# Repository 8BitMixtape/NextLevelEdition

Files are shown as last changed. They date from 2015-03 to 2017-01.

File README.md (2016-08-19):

NextLevelEdition
================

SMD 32U4 Massproduction Ready PCB that fits in Mixtape

How to install
================
Download Hardware Cores from Sparkfun:
https://learn.sparkfun.com/tutorials/pro-micro--fio-v3-hookup-guide/installing-mac--linux

For Linux udev rules needs to be changed:
http://forum.arduino.cc/index.php?topic=217910.0

```
/etc/udev/rules.d/70-persistent-net.rules

 # 8Bit Mixtape NextLevel Shit
 
ATTRS{idVendor}=="1b4f", ATTRS{idProduct}=="f100", ENV{ID_MM_DEVICE_IGNORE}="1"

ATTRS{idVendor}=="1b4f", ATTRS{idProduct}=="f101", ENV{ID_MM_DEVICE_IGNORE}="1"
```

Troubleshooting
================

If the serial port doesn't appear, see above.

Strange blinking: Did you attach the LiPo battery?

Bricked the board? if you choose the wrong board and upload this might happen. solder on the ISP plug and burn the bootloader. the files is in the core.

for linux:
`avrdude -P /dev/ttyACM0 -b 19200 -c avrisp -p m32u4 -v -e -U flash:w:Caterina-fio.hex:i`

Pins:
================

2 x Analog Input
----------------
A0 ( you can also only write 0) -> D18

A1 ( you can also only write 1) -> D19

2 x Digital Input / Buttons
---------------------------
D2 (2)

D3 (3)

Sound Output
------------
D9 (9) also connected to LED2

LEDs
----
D13 (13)

the middle i don't know. maybe charge state?

RX (0)

TX (1)

Timers
============

To change the prescaler of the timer connected to Pin9 (sound output)

```
TCCR1B = TCCR0B & 0b11111001; //no timer pre-scaler, fast PWM
```

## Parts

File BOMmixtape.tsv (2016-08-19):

References | Qty | Description | Mouser | Farnell
U1 | 1 | MCP73831 | 579-MCP73831T-2ATIOT | 1840935
U5 | 1 | ATMEGA32U4 | 556-ATMEGA32U4-MU | 2425127
U6 | 1 | MIC5219-3.3 | 998-MIC5219-3.3YM5TR | 2510252RL
Q1 | 1 | BSS123 | 512-BSS123 | 9845321
Y2 | 1 | 8MHz | 717-7B-8.000MAAJ-T | 2308726
C1, C13 | 2 | 10uF | 81-GRM31CR71A106KA01
C2,C3,C6,C8,C11,C12 | 6 | 1uF | 81-GRM188R61E105KA12
C4, C14 | 2 | 0.1uF | 81-GRM39X104K50D
C5, C7 | 2 | 22pF | 81-GRM39C220J50
C9 | 1 | 4.7uF | 81-GRM18R60J475KE19D
LED1 | 1 | Yellow | 859-LTST-C190KSKT
LED2 | 1 | Red | 859-LTST-C190KGKT
LED3 | 1 | Red | 859-LTST-C190KGKT
LED4 | 1 | Blue | 859-LTST-C190TBKT
LED5 | 1 | Yellow | 859-LTST-C190KSKT
R1, R2 | 2 | 33 | 667-ERJ-3GEYJ330V
R3, R4, R7, R10, R13, R16 | 6 | 330 | 667-ERJ-3GEYJ331V
R5 | 1 | 2K | 667-ERJ-3GEYJ222V
R6, R14, R15 | 3 | 10K | 667-ERJ-3GEYJ103V
R9 | 1 | 470 | 667-ERJ-3GEYJ470V
R11, R12 | 2 | 22 | 667-ERJ-3GEYJ220V
POT_LEFT | 1 |  | 652-PTV09A-4015UB103
POT_RIGHT | 1 |  | 652-PTV09A-4015UB103
S1 | 1 | Left | 693-1301.9317 | 1217767
S3 | 1 | Right | 693-1301.9317 | 1217767
SW | 1 | SWITCH_SMD, SS SMD402, reichelt.de
SD | 1 | MICROSD | 710-693071010811 | 2081363
SPEAKER | 1 | PS603SPK | 665-AS01508MRR
X1 | 1 | USB_B_SMD | 649-10118192-0001LF | 2506104
X2 | 1 | PJ-327A, ebay
Accu | 1 | AKKU IPD SH 1G, reichelt.de

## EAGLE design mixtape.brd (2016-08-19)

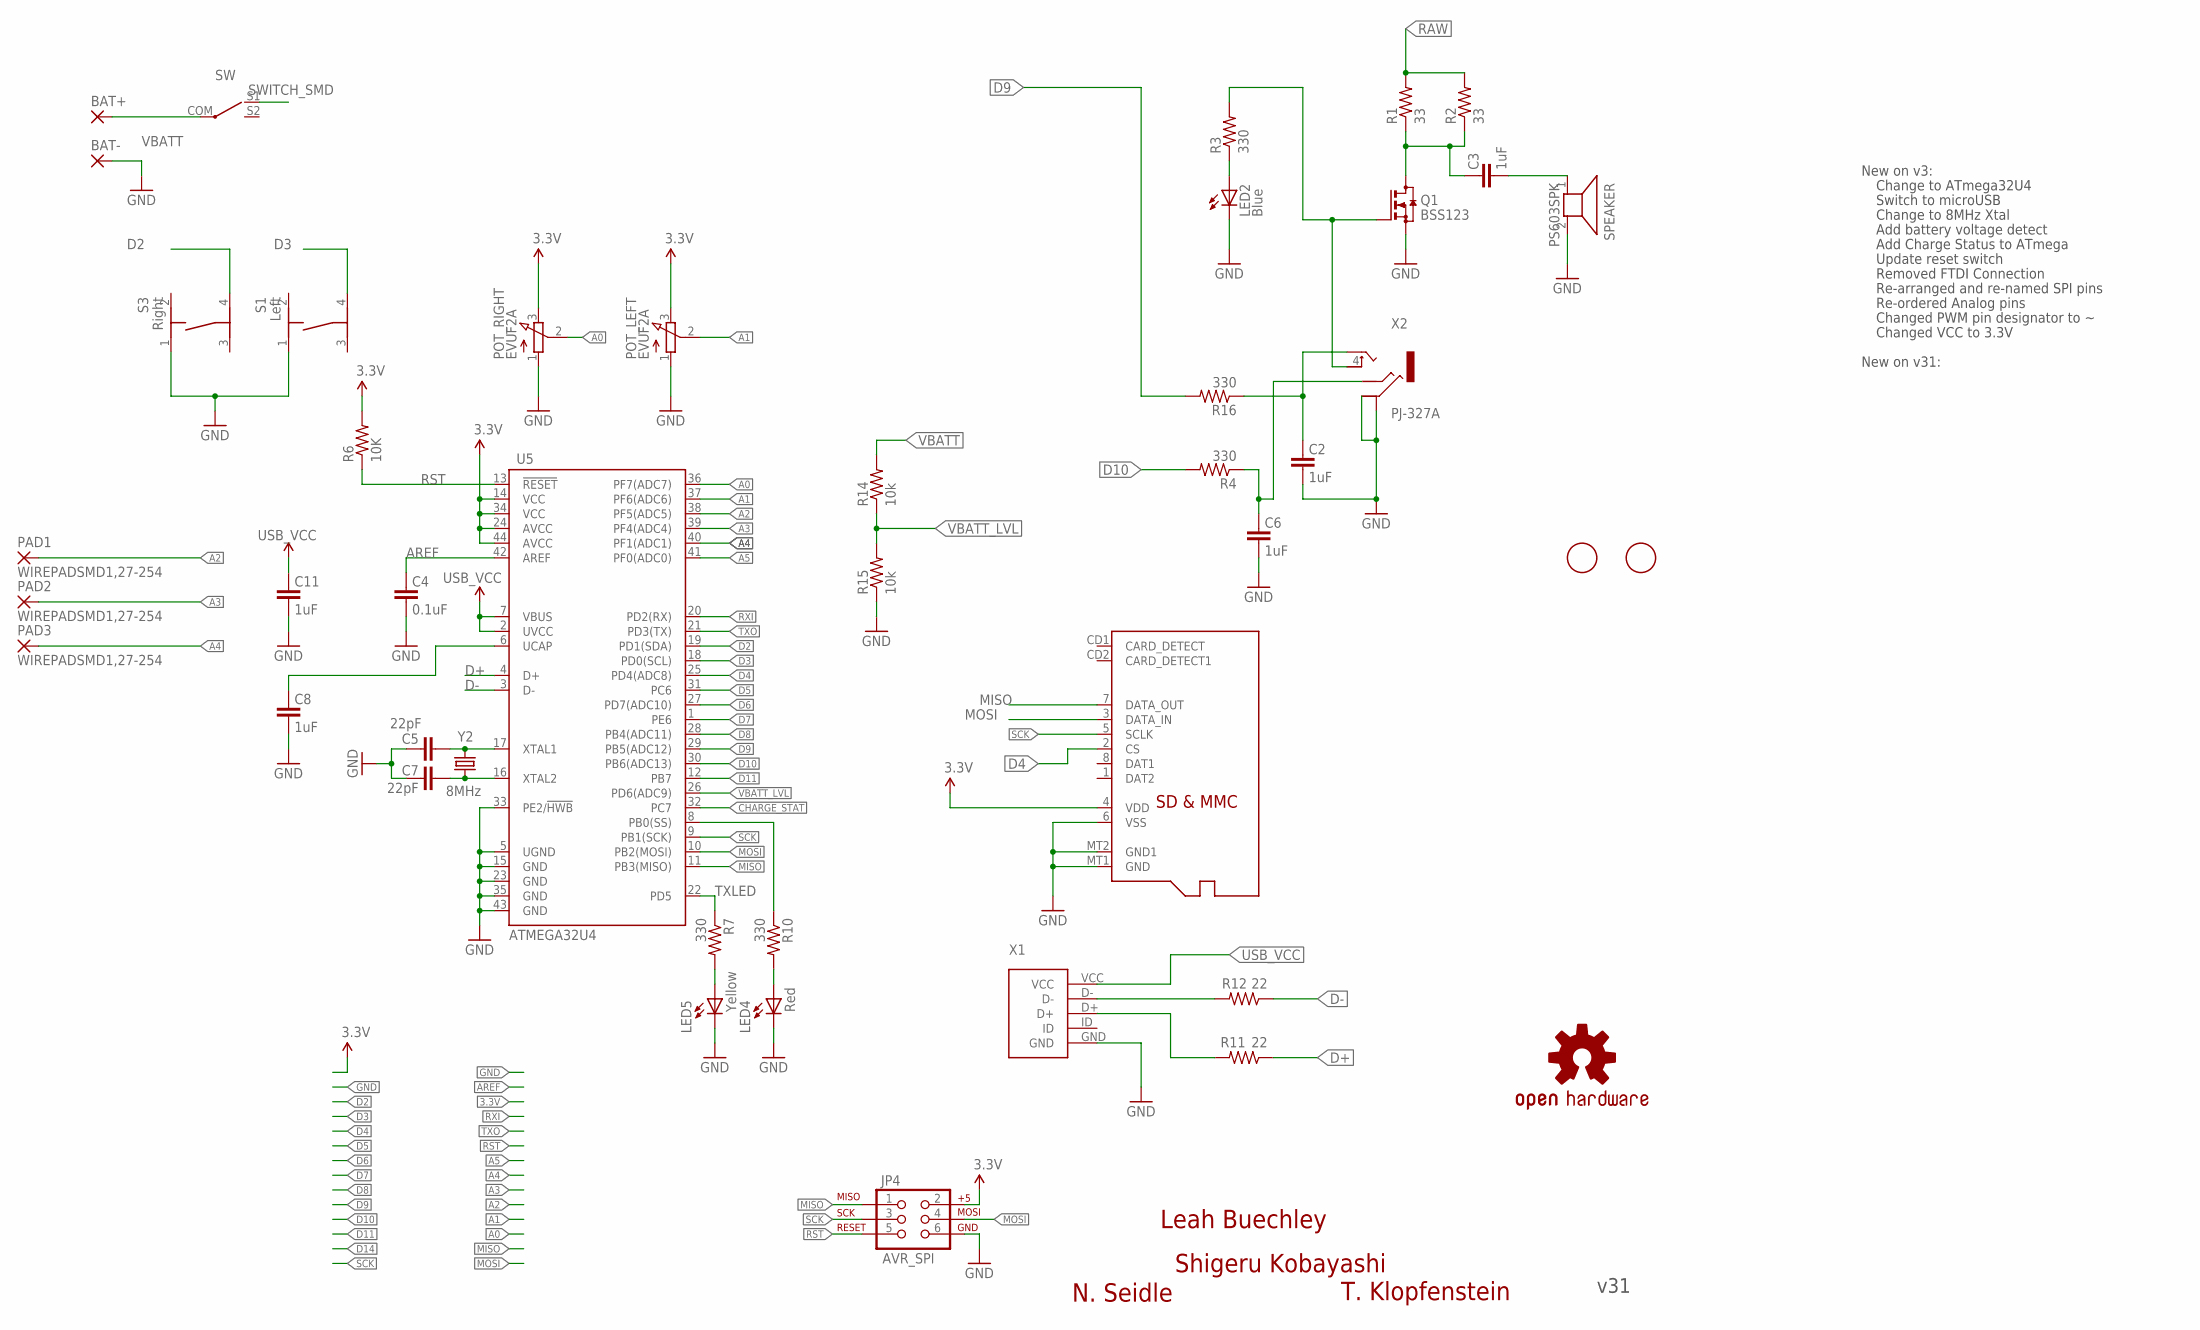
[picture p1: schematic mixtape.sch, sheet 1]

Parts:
BAT+: SMD5; SMD2,54-5,08
BAT-: SMD5; SMD2,54-5,08
C2, C3, C6, C8, C11: 1uF; 0603-CAP
C4: 0.1uF; 0603-CAP
C5, C7: 22pF; 0603-CAP
JP4: AVR_SPI; 2X3
LED2: Blue; LED-0603
LED4: Red; LED-0603
LED5: Yellow; LED-0603
LOGO1: OSHW-LOGOL; OSHW-LOGO-L
PAD1, PAD2, PAD3: WIREPADSMD1,27-254; SMD1,27-2,54
POT_LEFT: EVUF2A; EVUF
POT_RIGHT: EVUF2A; EVUF
Q1: BSS123; SOT23
R1, R2: 33; 0603-RES
R3, R4, R7, R10, R16: 330; 0603-RES
R6: 10K; 0603-RES
R11, R12: 22; 0603-RES
R14, R15: 10k; 0603-RES
S1: Left; TASTER-9314_SMD
S3: Right; TASTER-9314_SMD
SD: MICROSD
SPEAKER: PS603SPK; PS603
SW: SWITCH_SMD
U5: ATMEGA32U4; QFN-44-NOPAD_1:1
U$1, U$2: FIDUCIAL; FIDUCIAL_1MM
X1: USB_B_SMD
X2: PJ-327A
Y2: 8MHz; CRYSTAL-SMD-5X3

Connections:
3.3V: JP4.2, POT_LEFT.3 (E), POT_RIGHT.3 (E), R6.2, SD.4 (VDD), U5.14 (VCC), U5.24 (AVCC), U5.34 (VCC), U5.44 (AVCC); also elsewhere on the board
A0: POT_RIGHT.2 (S), U5.36 (PF7(ADC7))
A1: POT_LEFT.2 (S), U5.37 (PF6(ADC6))
A2: PAD1.1, U5.38 (PF5(ADC5))
A3: PAD2.1, U5.39 (PF4(ADC4))
A4: PAD3.1, U5.40 (PF1(ADC1))
A5: U5.41 (PF0(ADC0))
AREF: C4.2, U5.42 (AREF)
CHARGE_STAT: U5.32 (PC7); also elsewhere on the board
D2: S3.4, U5.19 (PD1(SDA))
D3: S1.4, U5.18 (PD0(SCL))
D4: SD.2 (CS), U5.25 (PD4(ADC8))
D5: U5.31 (PC6)
D6: U5.27 (PD7(ADC10))
D7: U5.1 (PE6)
D8: U5.28 (PB4(ADC11))
D9: R16.2, U5.29 (PB5(ADC12))
D10: R4.2, U5.30 (PB6(ADC13))
D11: U5.12 (PB7)
D14: R10.1, U5.8 (PB0(SS))
D+: R11.1, U5.4 (D+)
D-: R12.1, U5.3 (D-)
GND: BAT-.1, C2.1, C4.1, C5.2, C6.1, C7.2, C8.1, C11.1, JP4.6, LED2.C, LED4.C, LED5.C, POT_LEFT.1 (A), POT_RIGHT.1 (A), Q1.2 (S), R15.1, S1.1, S3.1, SD.6 (VSS), SD.MT1 (GND), SD.MT2 (GND1), SPEAKER.2, U5.5 (UGND), U5.15 (GND), U5.23 (GND), U5.33 (PE2/!HWB), U5.35 (GND), U5.43 (GND), X1.GND, X2.1, X2.5; also elsewhere on the board
MISO: JP4.1, SD.7 (DATA_OUT), U5.11 (PB3(MISO))
MOSI: JP4.4, SD.3 (DATA_IN), U5.10 (PB2(MOSI))
unnamed: C3.2, Q1.3 (D), R1.1, R2.1
unnamed: C3.1, SPEAKER.1
unnamed: C6.2, R4.1, X2.3
unnamed: R11.2, X1.D+
unnamed: LED2.A, R3.1
unnamed: Q1.1 (G), R3.2, X2.4
unnamed: LED5.A, R7.2
unnamed: C7.1, U5.16 (XTAL2), Y2.1
unnamed: C5.1, U5.17 (XTAL1), Y2.3 (2)
unnamed: LED4.A, R10.2
unnamed: R12.2, X1.D-
unnamed: C2.2, R16.1, X2.2
RAW: R1.2, R2.2, SW.S1; also elsewhere on the board
RST: JP4.5, R6.1, U5.13 (!RESET)
RXI: U5.20 (PD2(RX))
SCK: JP4.3, SD.5 (SCLK), U5.9 (PB1(SCK))
TXLED: R7.1, U5.22 (PD5)
TXO: U5.21 (PD3(TX))
UCAP: C8.2, U5.6 (UCAP)
USB_VCC: C11.2, U5.2 (UVCC), U5.7 (VBUS), X1.VCC; also elsewhere on the board
VBATT: BAT+.1, R14.2, SW.COM; also elsewhere on the board
VBATT_LVL: R14.1, R15.2, U5.26 (PD6(ADC9))

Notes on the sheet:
Shigeru Kobayashi
Change to ATmega32U4
Switch to microUSB
New on v3:
Change to 8MHz Xtal
Add battery voltage detect
Add Charge Status to ATmega
Update reset switch
Removed FTDI Connection
Re-arranged and re-named SPI pins
Re-ordered Analog pins
Changed PWM pin designator to ~
Changed VCC to 3.3V
New on v31:
v31
N. Seidle
T. Klopfenstein
Leah Buechley

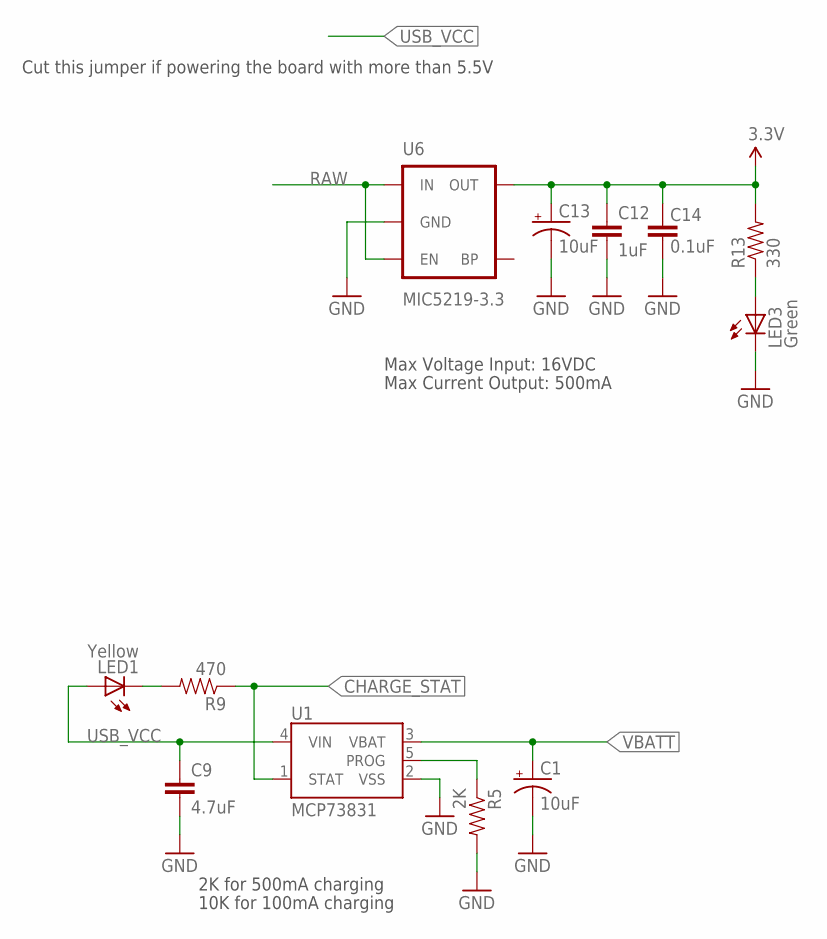
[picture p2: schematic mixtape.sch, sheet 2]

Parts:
C1, C13: 10uF; EIA3216
C9: 4.7uF; 0603-CAP
C12: 1uF; 0603-CAP
C14: 0.1uF; 0603-CAP
LED1: Yellow; LED-0603
LED3: Green; LED-0603
R5: 2K; 0603-RES
R9: 470; 0603-RES
R13: 330; 0603-RES
U1: MCP73831; SOT23-5
U6: MIC5219-3.3; SOT23-5

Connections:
3.3V: C12.1, C13.A (+), C14.2, R13.2, U6.5 (OUT); also elsewhere on the board
CHARGE_STAT: R9.1, U1.1 (STAT); also elsewhere on the board
GND: C1.C (-), C9.2, C12.2, C13.C (-), C14.1, LED3.C, R5.2, U1.2 (VSS), U6.2 (GND); also elsewhere on the board
unnamed: LED1.C, R9.2
unnamed: R5.1, U1.5 (PROG)
unnamed: LED3.A, R13.1
RAW: U6.1 (IN), U6.3 (EN); also elsewhere on the board
USB_VCC: C9.1, LED1.A, U1.4 (VIN); also elsewhere on the board
VBATT: C1.A (+), U1.3 (VBAT); also elsewhere on the board

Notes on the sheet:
Max Voltage Input: 16VDC
Max Current Output: 500mA
Cut this jumper if powering the board with more than 5.5V
2K for 500mA charging
10K for 100mA charging

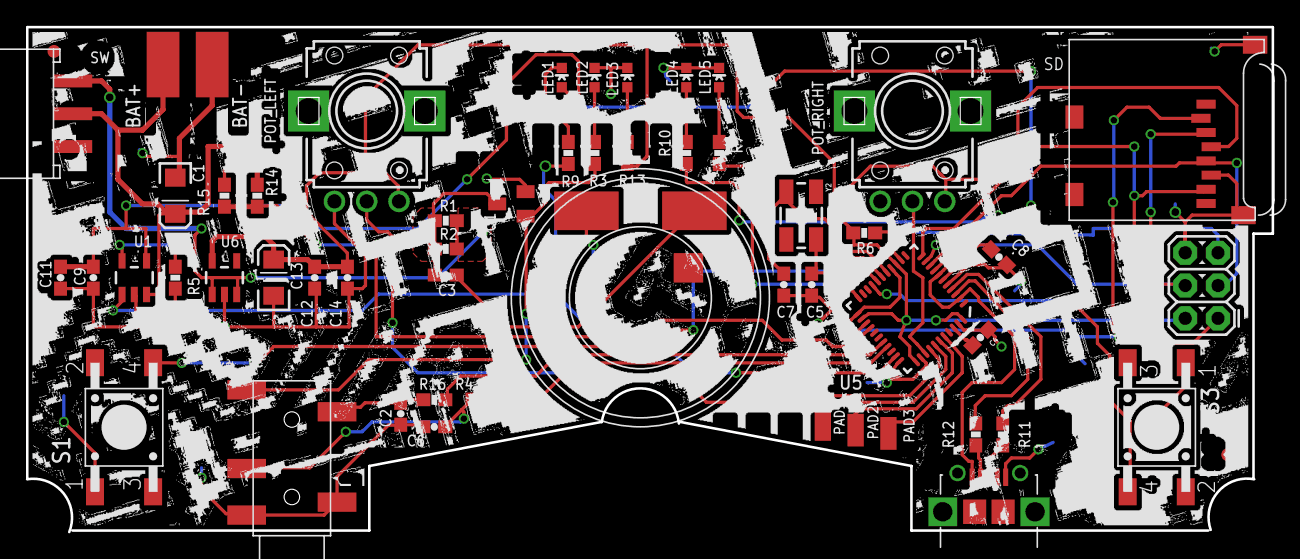
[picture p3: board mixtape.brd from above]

Board: 4 copper layers, 96.5 x 39.1 mm, 57 parts (1 on the bottom side), 42 nets.

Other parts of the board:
U$4: FIO_LOGOV2; FUNNEL_LOGO_BOTTOM_V2

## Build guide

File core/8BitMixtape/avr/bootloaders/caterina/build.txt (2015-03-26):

make clean
make PID=0x9209 F_CPU=16000000
copy Caterina.hex Caterina-wiflyin.hex
make clean
make PID=0x9207 F_CPU=8000000
copy Caterina.hex Caterina-lilypadusb.hex
make clean
make PID=0x9205 F_CPU=16000000
copy Caterina.hex Caterina-promicro16.hex
make clean
make PID=0x9203 F_CPU=8000000
copy Caterina.hex Caterina-promicro8.hex 
make clean
make PID=0x2B74 F_CPU=16000000
copy Caterina.hex Caterina-makey.hex
make clean
make PID=0xF100 F_CPU=8000000
copy Caterina.hex Caterina-fio.hex
make clean
make PID=0x920B F_CPU=16000000
copy Caterina.hex Caterina-minibench.hex

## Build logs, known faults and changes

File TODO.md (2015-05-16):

NextLevelEdition
================

SMD 32U4 Massproduction Ready PCB that fits in Mixtape

TO DO LIST
================
* create BOM

OTHER IDEAS
================

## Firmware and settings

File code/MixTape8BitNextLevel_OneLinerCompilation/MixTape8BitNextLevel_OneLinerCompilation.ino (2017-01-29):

// 8-Bit Mixtape Next-Level Edition by GaudiLabs

// one-line algorithmic music
// see viznut's blog http://countercomplex.blogspot.com/2011/10/algorithmic-symphonies-from-one-line-of.html
// and http://www.youtube.com/watch?v=GtQdIYUtAHg&feature=related

// Player ported to arduino by stimmer


#include <SD.h>                      // need to include the SD library
//#define SD_ChipSelectPin 53  //example uses hardware SS pin 53 on Mega2560
#define SD_ChipSelectPin 4  //using digital pin 4 on arduino nano 328, can use other pins
#include <TMRpcm.h>           //  also need to include this library...
#include <SPI.h>

TMRpcm tmrpcm;   // create an object for use in this sketch

unsigned long time = 0;

const int buttonPinRight = 2;    // the number of the pushbutton pin
const int buttonPinLeft = 3;    // the number of the pushbutton pin
const int potPinRight = A0;    // the number of the pushbutton pin
const int potPinLeft = A1;    // the number of the pushbutton pin

int RXLED = 17;  // The RX LED has a defined Arduino pin


const int outPinR = 9;
const int outPinL = 10;


uint8_t song = 1; 
int reading;

int aL;
int aR;

bool synth_mode=false;
bool intro=true;
static int del = 0; 
  long t = 0; 
byte v0 = 0; 
byte v1 = 0; 

unsigned int c3 = 1;
unsigned int c4 = 130;

const uint8_t noSongs = 84;    // the number of the pushbutton pin
char* myPlaylist[]=
{
  "1", 
  "2", 
  "3",
  "4", 
  "5",
  "6",
  "7",
  "8",
  "9",
  "10",
  "11",
  "12",
  "13",
  "14",
  "15",
  "16",
  "17",
  "18",
  "19",
  "20",
  "21"
  };


void setup(){
pinMode(buttonPinLeft,INPUT);
pinMode(buttonPinRight,INPUT);
digitalWrite(buttonPinLeft,HIGH);
digitalWrite(buttonPinRight,HIGH);

 TXLED1; //TX LED is not tied to a normally controlled pin



  tmrpcm.speakerPin = 9; //5,6,11 or 46 on Mega, 9 on Uno, Nano, etc
  //Complimentary Output or Dual Speakers:
  // Library angepasst, complementary output entfernt - Urs.

  pinMode(10,OUTPUT); //Pin pairs: 9,10 Mega: 5-2,6-7,11-12,46-45 
  
  Serial.begin(115200);
  pinMode(13,OUTPUT); //LED Connected to analog pin 0
  if (!SD.begin(SD_ChipSelectPin)) {  // see if the card is present and can be initialized:
    Serial.println("SD fail");  
    return;   // don't do anything more if not

  }
  else{   
    Serial.println("SD ok");   
  }





  pinMode(outPinR, OUTPUT);
  pinMode(outPinL, OUTPUT);

TCCR1A = (1<<COM1A1) | (1<<COM1B1) | (1<<WGM10) ;// 161; 
TCCR1B = (1<<CS10);

ADCSRA &= ~((1<<ADPS2)|(1<<ADPS1)|(1<<ADPS0));

  tmrpcm.play("Gaudi"); //the sound file "music" will play each time the arduino powers up, or is reset
intro=true;



}


void putb(byte b)
{
 static long m;
  
 if ((micros()-m)>c4)  digitalWrite(RXLED, HIGH); else digitalWrite(RXLED, LOW);    // set the LED on
 while(micros()-m <c4);
 m=micros();
 
OCR1A=b;
OCR1B=b;

}


void loop(){  

 for(long t=0;;t++){

c3=analogRead(potPinRight);
c4=analogRead(potPinLeft);
if (c4>300) c4=c4-150; else {t++;c4=c4;};


 switch(song){


// ====== 1ST ITERATION ======


case 1:
if (intro) tmrpcm.play("FIRSTviz"); else {
  if (c3<10) c3=63<<3;
// viznut 2011-09-18 http://www.youtube.com/watch?v=GtQdIYUtAHg
v0=t*(((t>>12)|(t>>8))&((c3>>3)&(t>>4)));
}
break;

case 2:
if (intro) tmrpcm.play("tejeez"); else {
  if (c3<10) c3=1<<6;
// tejeez 2011-09-18 http://www.youtube.com/watch?v=GtQdIYUtAHg
v0=((c3>>6)*t*(t>>5|t>>8))>>(t>>16);
}
break;

case 3:
if (intro) tmrpcm.play("visy"); else {
  if (c3<10) c3=25<<5;
// visy 2011-09-18 http://www.youtube.com/watch?v=GtQdIYUtAHg
v0=t*(((t>>9)|(t>>13))&((c3>>5)&(t>>6)));
}
break;

case 4:
if (intro) tmrpcm.play("tejeez2"); else {
  if (c3<10) c3=123<<2;
// tejeez 2011-09-18 http://www.youtube.com/watch?v=GtQdIYUtAHg
v0=t*(((t>>11)&(t>>8))&((c3>>2)&(t>>3)));
}
break;

case 5:
if (intro) tmrpcm.play("visy2"); else {
  if (c3<10) c3=20<<5;
// visy 2011-09-18 http://www.youtube.com/watch?v=GtQdIYUtAHg
v0=t*(t>>8*((t>>15)|(t>>8))&((c3>>5)|(t>>19)*5>>t|(t>>3)));
}
break;

case 6:
if (intro) tmrpcm.play("tejeez3"); else {
  if (c3<10) c3=234<<1;
// tejeez 2011-09-18 http://www.youtube.com/watch?v=GtQdIYUtAHg
v0=((-t&4095)*(255&t*(t&(t>>13)))>>12)+(127&t*((c3>>1)&t>>8&t>>3)>>(3&t>>14));
}
break;

case 7:
if (intro) tmrpcm.play("spacepo"); else {
  if (c3<10) c3=63<<3;
// visy 2011-09-18 http://www.youtube.com/watch?v=GtQdIYUtAHg "Space Invaders vs Pong"
v0=t*(t>>((t>>9)|(t>>8))&((c3>>3)&(t>>4)));
}
break;

// ====== 2ND ITERATION ======

case 8:
if (intro) tmrpcm.play("visy3"); else {
  if (c3<10) c3=10<<6;
// viznut 2011-09-30 http://www.youtube.com/watch?v=qlrs2Vorw2Y
v0=(t>>6|t|t>>(t>>16))*(c3>>6)+((t>>11)&7);
}
break;

case 9:
if (intro) tmrpcm.play("pyryp"); else {
  if (c3<10) c3=69<<3;
// pyryp 2011-09-30 http://www.youtube.com/watch?v=qlrs2Vorw2Y
v0=(v0>>1)+(v0>>4)+t*(((t>>16)|(t>>6))&((c3>>3)&(t>>9)));
}
break;

case 10:
if (intro) tmrpcm.play("red"); else {
  if (c3<10) c3=63<<3;
// red- 2011-09-30 http://www.youtube.com/watch?v=qlrs2Vorw2Y
v0=(t|(t>>9|t>>7))*t&(t>>11|t>>9);
}
break;

case 11:
if (intro) tmrpcm.play("miiro"); else {
  if (c3<10) c3=5<<7;
// miiro 2011-09-30 http://www.youtube.com/watch?v=qlrs2Vorw2Y
v0=t*(c3>>7)&(t>>7)|t*3&(t*4>>10);
}
break;

case 12:
if (intro) tmrpcm.play("varjo"); else {
  if (c3<10) c3=10<<6;
// viznut 2011-09-30 http://www.youtube.com/watch?v=qlrs2Vorw2Y (xpansive+varjohukka)
v0=(t>>7|t|t>>6)*(c3>>6)+4*(t&t>>13|t>>6);
}
break;

case 13:
if (intro) tmrpcm.play("skurk"); else {
  if (c3<10) c3=8192>>3;
// skurk+raer 2011-09-30 http://www.youtube.com/watch?v=qlrs2Vorw2Y
v0=((t&4096)?((t*(t^t%255)|(t>>4))>>1):(t>>3)|((t&(c3<<3))?t<<2:t));
}
break;

case 14:
if (intro) tmrpcm.play("lost"); else {
  if (c3<10) c3=46<<3;
// xpansive 2011-09-29 http://pouet.net/topic.php?which=8357&page=2 "Lost in Space"
v0=((t*(t>>8|t>>9)&(c3>>3)&t>>8))^(t&t>>13|t>>6);
}
break;


// ====== 3RD ITERATION ======














case 15:   v0=((t/2*(15&(0x234568a0>>(t>>8&28))))|t/2>>(t>>11)^t>>12)+(t/16&t&24);break;
case 16:   v0=(t&t%255)-(t*3&t>>13&t>>6);break;
case 17:    v0=t>>4|t&((t>>5)/(t>>7-(t>>15)&-t>>7-(t>>15)));break;
case 18:    v0=((t*("36364689"[t>>13&7]&15))/12&128)+(((((t>>12)^(t>>12)-2)%11*t)/4|t>>13)&127) ;break;
case 19:    v0=(t*9&t>>4|t*5&t>>7|t*3&t/1024)-1;break;
case 20:    v0=((t*(t>>12)&(201*t/100)&(199*t/100))&(t*(t>>14)&(t*301/100)&(t*399/100)))+((t*(t>>16)&(t*202/100)&(t*198/100))-(t*(t>>17)&(t*302/100)&(t*298/100)))  ;break;  
case 21:    v0=((t*(t>>12)&(201*t/100)&(199*t/100))&(t*(t>>14)&(t*301/100)&(t*399/100)))+((t*(t>>16)&(t*202/100)&(t*198/100))-(t*(t>>18)&(t*302/100)&(t*298/100)));break;
case 22:    v0=t*(t^t+(t>>15|1)^(t-1280^t)>>10);break;
case 23:    v0=((t>>1%128)+20)*3*t>>14*t>>18 ;break;
case 24:    v0=t*(((t>>9)&10)|((t>>11)&24)^((t>>10)&15&(t>>15)));break;
case 25:    v0=(t*t/256)&(t>>((t/1024)%16))^t%64*(0xC0D3DE4D69>>(t>>9&30)&t%32)*t>>18;break;
case 26:    v0=t*(42&t>>10);break;
case 27:    v0=t&t>>8;break;


case 28:
if (intro) tmrpcm.play("42melody"); else {
  if (c3<10) c3=672;
// "the 42 melody", separately discovered by several people on irc etc
v0=t*((c3>>4)&t>>10);
}

break;



case 29:    
// danharaj 2011-10-03 http://www.reddit.com/r/programming/comments/kyj77/algorithmic_symphonies_from_one_line_of_code_how/ "fractal trees", 216's version
v0=t|t%255|t%257;break;

case 30:    
// droid 2011-10-05 http://pouet.net/topic.php?which=8357&page=10
v0=t>>6&1?t>>5:-t>>4;break;

case 31: 
// Niklas_Roy 2011-10-14 http://countercomplex.blogspot.com/2011/10/algorithmic-symphonies-from-one-line-of.html
v0= t*(t>>9|t>>13)&16;break;

case 32:
// krcko 2011-10-04 http://rafforum.rs/index.php/topic,123.0.html
v0=(t&t>>12)*(t>>4|t>>8);break;

case 33:
// viznut 2011-10-10 http://www.youtube.com/watch?v=tCRPUv8V22o
v0=(t*5&t>>7)|(t*3&t>>10);break;

case 34:
// tejeez 2011-09-18 http://www.youtube.com/watch?v=GtQdIYUtAHg
v0=(t*(t>>5|t>>8))>>(t>>16);break;

case 35:
// miiro 2011-09-30 http://www.youtube.com/watch?v=qlrs2Vorw2Y
if (intro) tmrpcm.play("miiro"); else v0=t*5&(t>>7)|t*3&(t*4>>10);
break;

case 36:
// robert 2011-10-11 http://countercomplex.blogspot.com/2011/10/algorithmic-symphonies-from-one-line-of.html
if (intro) tmrpcm.play("robert"); else v0=(t>>13|t%24)&(t>>7|t%19);
break;

case 37:
if (intro) tmrpcm.play("Niklas"); else v0=(t*((t>>9|t>>13)&15))&129;//the sound file "music" will play each time the arduino powers up, or is reset
// Niklas_Roy 2011-10-14 http://countercomplex.blogspot.com/2011/10/algorithmic-symphonies-from-one-line-of.html
break;

case 38:
// viznut 2011-10-10 http://www.youtube.com/watch?v=tCRPUv8V22o  
v0=(t&t%255)-(t*3&t>>13&t>>6);break;

case 39:
// krcko 2011-10-04 http://rafforum.rs/index.php/topic,123.0.html
v0=(t&t>>12)*(t>>4|t>>8)^t>>6;break;

case 40:
// blueberry 2011-10-05 http://pouet.net/topic.php?which=8357&page=12 11kHz
v0=t*(((t>>9)^((t>>9)-1)^1)%13);break;

case 41:
// rrola 2011-10-04 http://pouet.net/topic.php?which=8357&page=9 optimized by ryg
v0=t*(0xCA98>>(t>>9&14)&15)|t>>8;break;

case 42:
// tonic 2011-10-01 http://pouet.net/topic.php?which=8357&page=5 "mr. arpeggiator playing a solo"
v0=(t/8)>>(t>>9)*t/((t>>14&3)+4);break;

case 43:
// FreeFull 2011-10-12 http://countercomplex.blogspot.com/2011/10/algorithmic-symphonies-from-one-line-of.html
v0=(~t/100|(t*3))^(t*3&(t>>5))&t;break;

case 44:
// red- 2011-09-30 http://www.youtube.com/watch?v=qlrs2Vorw2Y
v0=(t|(t>>9|t>>7))*t&(t>>11|t>>9);break;

case 45:
// harism 2011-10-09 http://0xa.kuri.mu/2011/10/09/bitop-videos/
v0=((t>>1%128)+20)*3*t>>14*t>>18 ;break;

case 47:
// viznut 2011-09-18 http://www.youtube.com/watch?v=GtQdIYUtAHg
v0=t*(((t>>12)|(t>>8))&(63&(t>>4)));break;

case 48:
// visy 2011-09-18 http://www.youtube.com/watch?v=GtQdIYUtAHg
v0=t*(((t>>9)|(t>>13))&(25&(t>>6)));break;

case 49:
// 216 2011-10-10 http://www.youtube.com/watch?v=tCRPUv8V22o
v0=t*(t^t+(t>>15|1)^(t-1280^t)>>10);break;

case 50:
// tejeez 2011-09-18 http://www.youtube.com/watch?v=GtQdIYUtAHg
v0=t*(((t>>11)&(t>>8))&(123&(t>>3)));break;

case 51:
// viznut 2011-09-30 http://www.youtube.com/watch?v=qlrs2Vorw2Y (xpansive+varjohukka)
v0=(t>>7|t|t>>6)*10+4*(t&t>>13|t>>6);break;

case 52:
// stephth 2011-10-03 http://news.ycombinator.com/item?id=3063359
v0=(t*9&t>>4|t*5&t>>7|t*3&t/1024)-1;break;

case 53:
// visy 2011-09-18 http://www.youtube.com/watch?v=GtQdIYUtAHg "Space Invaders vs Pong"
v0=t*(t>>((t>>9)|(t>>8))&(63&(t>>4)));break;

case 54:
// viznut 2011-09-30 http://www.youtube.com/watch?v=qlrs2Vorw2Y
v0=(t>>6|t|t>>(t>>16))*10+((t>>11)&7);break;

case 55:
// yumeji 2011-10-04 http://pouet.net/topic.php?which=8357&page=9
v0=(t>>1)*(0xbad2dea1>>(t>>13)&3)|t>>5;break;

case 56:
// ryg 2011-10-04 http://pouet.net/topic.php?which=8357&page=8
v0=(t>>4)*(13&(0x8898a989>>(t>>11&30)));break;

case 57:
// marmakoide 2011-10-04 http://pouet.net/topic.php?which=8357&page=8
v0=(t>>(t&7))|(t<<(t&42))|(t>>7)|(t<<5);break;

case 58:
// robert 2011-10-11 http://countercomplex.blogspot.com/2011/10/algorithmic-symphonies-from-one-line-of.html
v0=(t>>7|t%45)&(t>>8|t%35)&(t>>11|t%20);break;

case 59:
// lucasvb 2011-10-03 http://www.reddit.com/r/programming/comments/kyj77/algorithmic_symphonies_from_one_line_of_code_how/
v0=(t>>6|t<<1)+(t>>5|t<<3|t>>3)|t>>2|t<<1;break;

case 60:
// bear @ celephais
v0=t+(t&t^t>>6)-t*((t>>9)&(t%16?2:6)&t>>9);break;

case 61:
// xpansive 2011-09-29 http://pouet.net/topic.php?which=8357&page=2 "Lost in Space"
v0=((t*(t>>8|t>>9)&46&t>>8))^(t&t>>13|t>>6);break;

case 63:
// marmakoide 2011-10-03 http://pouet.net/topic.php?which=8357&page=7 "Lemmings March"
v0=(t>>5)|(t<<4)|((t&1023)^1981)|((t-67)>>4);break;

case 64:
// droid 2011-10-04 http://pouet.net/topic.php?which=8357&page=9
v0=t>>4|t&(t>>5)/(t>>7-(t>>15)&-t>>7-(t>>15));break;

case 65:
// rez 2011-10-03 http://pouet.net/topic.php?which=8357&page=7
v0=t*(t/256)-t*(t/255)+t*(t>>5|t>>6|t<<2&t>>1);break;

case 66:
// viznut 2011-10-06 #countercomplex "moon scanner generalization", based on jaffa's formula
v0=((t>>5&t)-(t>>5)+(t>>5&t))+(t*((t>>14)&14));break;

case 67:
// viznut 2011-10-04 http://pouet.net/topic.php?which=8357&page=9
v0=(t*((3+(1^t>>10&5))*(5+(3&t>>14))))>>(t>>8&3);break;

case 69:
// pyryp 2011-09-30 http://www.youtube.com/watch?v=qlrs2Vorw2Y
//v0==(v0=>>1)+(v0=>>4)+t*(((t>>16)|(t>>6))&(69&(t>>9)));break;


case 83:

v0=t*6 & (t>>7|(int)(t*3.5)<<2) | t*4 & ((t>>8|(int)(t*1.5)<<2)) | t*4 & (((int)(t/1.5)>>7)^((int)(t/3)>>8)^((int)(t/6)>>9)); break;


case 84:
// raer 2011-10-07 http://pouet.net/topic.php?which=8357&page=16 stereo 11kHz
v0= ((t&4096)?((t*(t^t%255)|(t>>4))>>1):(t>>3)|((t&8192)?t<<2:t));
v1= t*(((t>>9)^((t>>9)-1)^1)%13);break;

    default: break;
    
 }
  


if (!(tmrpcm.isPlaying())) putb(v0);
intro=false;
 
       if(digitalRead(buttonPinRight) == LOW) {while (digitalRead(buttonPinRight) == LOW); delayMicroseconds(1000); song++; intro=true;if (song>(noSongs-1)) song=noSongs-1;}
       if(digitalRead(buttonPinLeft) == LOW)  {while (digitalRead(buttonPinLeft) == LOW); delayMicroseconds(1000); song--; intro=true;if (song==0)song=1;}





       


 }
}

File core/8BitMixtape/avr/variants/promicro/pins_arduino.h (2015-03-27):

/*
  pins_arduino.h - Pin definition functions for Arduino
  Part of Arduino - http://www.arduino.cc/

  Copyright (c) 2007 David A. Mellis

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
  $Id: wiring.h 249 2007-02-03 16:52:51Z mellis $
*/

#ifndef Pins_Arduino_h
#define Pins_Arduino_h

#include <avr/pgmspace.h>

#define TX_RX_LED_INIT	DDRD |= (1<<5), DDRB |= (1<<0)
#define TXLED0			PORTD |= (1<<5)
#define TXLED1			PORTD &= ~(1<<5)
#define RXLED0			PORTB |= (1<<0)
#define RXLED1			PORTB &= ~(1<<0)

#define NUM_ANALOG_INPUTS 12

static const uint8_t SDA = 2;
static const uint8_t SCL = 3;

// Map SPI port to 'new' pins D14..D17
static const uint8_t SS   = 17;
static const uint8_t MOSI = 16;
static const uint8_t MISO = 14;
static const uint8_t SCK  = 15;

// Mapping of analog pins as digital I/O
// A6-A11 share with digital pins
static const uint8_t A0 = 18;
static const uint8_t A1 = 19;
static const uint8_t A2 = 20;
static const uint8_t A3 = 21;
static const uint8_t A4 = 22;
static const uint8_t A5 = 23;
static const uint8_t A6 = 24;	// D4
static const uint8_t A7 = 25;	// D6
static const uint8_t A8 = 26;	// D8
static const uint8_t A9 = 27;	// D9
static const uint8_t A10 = 28;	// D10
static const uint8_t A11 = 29;	// D12

#define digitalPinToPCICR(p)    ((((p) >= 8 && (p) <= 11) || ((p) >= 14 && (p) <= 17) || ((p) >= A8 && (p) <= A10)) ? (&PCICR) : ((uint8_t *)0))
#define digitalPinToPCICRbit(p) 0
#define digitalPinToPCMSK(p)    ((((p) >= 8 && (p) <= 11) || ((p) >= 14 && (p) <= 17) || ((p) >= A8 && (p) <= A10)) ? (&PCMSK0) : ((uint8_t *)0))
#define digitalPinToPCMSKbit(p) ( ((p) >= 8 && (p) <= 11) ? (p) - 4 : ((p) == 14 ? 3 : ((p) == 15 ? 1 : ((p) == 16 ? 2 : ((p) == 17 ? 0 : (p - A8 + 4))))))

//	__AVR_ATmega32U4__ has an unusual mapping of pins to channels
extern const uint8_t PROGMEM analog_pin_to_channel_PGM[];
#define analogPinToChannel(P)  ( pgm_read_byte( analog_pin_to_channel_PGM + (P) ) )

#ifdef ARDUINO_MAIN

// On the Arduino board, digital pins are also used
// for the analog output (software PWM).  Analog input
// pins are a separate set.

// ATMEL ATMEGA32U4 / ARDUINO LEONARDO
//
// D0				PD2					RXD1/INT2
// D1				PD3					TXD1/INT3
// D2				PD1		SDA			SDA/INT1
// D3#				PD0		PWM8/SCL	OC0B/SCL/INT0
// D4		A6		PD4					ADC8
// D5#				PC6		???			OC3A/#OC4A
// D6#		A7		PD7		FastPWM		#OC4D/ADC10
// D7				PE6					INT6/AIN0
//
// D8		A8		PB4					ADC11/PCINT4
// D9#		A9		PB5		PWM16		OC1A/#OC4B/ADC12/PCINT5
// D10#		A10		PB6		PWM16		OC1B/0c4B/ADC13/PCINT6
// D11#				PB7		PWM8/16		0C0A/OC1C/#RTS/PCINT7
// D12		A11		PD6					T1/#OC4D/ADC9
// D13#				PC7		PWM10		CLK0/OC4A
//
// A0		D18		PF7					ADC7
// A1		D19		PF6					ADC6
// A2		D20 	PF5					ADC5
// A3		D21 	PF4					ADC4
// A4		D22		PF1					ADC1
// A5		D23 	PF0					ADC0
//
// New pins D14..D17 to map SPI port to digital pins
//
// MISO		D14		PB3					MISO,PCINT3
// SCK		D15		PB1					SCK,PCINT1
// MOSI		D16		PB2					MOSI,PCINT2
// SS		D17		PB0					RXLED,SS/PCINT0
//
// TXLED			PD5
// RXLED		    PB0
// HWB				PE2					HWB

// these arrays map port names (e.g. port B) to the
// appropriate addresses for various functions (e.g. reading
// and writing)
const uint16_t PROGMEM port_to_mode_PGM[] = {
	NOT_A_PORT,
	NOT_A_PORT,
	(uint16_t) &DDRB,
	(uint16_t) &DDRC,
	(uint16_t) &DDRD,
	(uint16_t) &DDRE,
	(uint16_t) &DDRF,
};

const uint16_t PROGMEM port_to_output_PGM[] = {
	NOT_A_PORT,
	NOT_A_PORT,
	(uint16_t) &PORTB,
	(uint16_t) &PORTC,
	(uint16_t) &PORTD,
	(uint16_t) &PORTE,
	(uint16_t) &PORTF,
};

const uint16_t PROGMEM port_to_input_PGM[] = {
	NOT_A_PORT,
	NOT_A_PORT,
	(uint16_t) &PINB,
	(uint16_t) &PINC,
	(uint16_t) &PIND,
	(uint16_t) &PINE,
	(uint16_t) &PINF,
};

const uint8_t PROGMEM digital_pin_to_port_PGM[30] = {
	PD, // D0 - PD2
	PD,	// D1 - PD3
	PD, // D2 - PD1
	PD,	// D3 - PD0
	PD,	// D4 - PD4
	PC, // D5 - PC6
	PD, // D6 - PD7
	PE, // D7 - PE6
	
	PB, // D8 - PB4
	PB,	// D9 - PB5
	PB, // D10 - PB6
	PB,	// D11 - PB7
	PD, // D12 - PD6
	PC, // D13 - PC7
	
	PB,	// D14 - MISO - PB3
	PB,	// D15 - SCK - PB1
	PB,	// D16 - MOSI - PB2
	PB,	// D17 - SS - PB0
	
	PF,	// D18 - A0 - PF7
	PF, // D19 - A1 - PF6
	PF, // D20 - A2 - PF5
	PF, // D21 - A3 - PF4
	PF, // D22 - A4 - PF1
	PF, // D23 - A5 - PF0
	
	PD, // D24 / D4 - A6 - PD4
	PD, // D25 / D6 - A7 - PD7
	PB, // D26 / D8 - A8 - PB4
	PB, // D27 / D9 - A9 - PB5
	PB, // D28 / D10 - A10 - PB6
	PD, // D29 / D12 - A11 - PD6
};
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

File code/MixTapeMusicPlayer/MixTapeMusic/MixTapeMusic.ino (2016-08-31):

#include <SD.h>                      // need to include the SD library
//#define SD_ChipSelectPin 53  //example uses hardware SS pin 53 on Mega2560
#define SD_ChipSelectPin 4  //using digital pin 4 on arduino nano 328, can use other pins
#include <TMRpcm.h>           //  also need to include this library...
#include <SPI.h>

TMRpcm tmrpcm;   // create an object for use in this sketch

unsigned long time = 0;

const int buttonPinRight = 2;    // the number of the pushbutton pin
const int buttonPinLeft = 3;    // the number of the pushbutton pin

int song = 0;    // the number of the pushbutton pin
int reading;

bool synth_mode=false;

  long t = 0; 
int v0 = 0; 
int v1 = 0; 

unsigned int c3 = 2000;
unsigned int c4 = 6;

const int noSongs = 4;    // the number of the pushbutton pin
char* myPlaylist[]=
{
  "1", 
  "2", 
  "3",
  "4", 
  "5",
  "6"};


void setup(){
pinMode(buttonPinLeft,INPUT);
pinMode(buttonPinRight,INPUT);
digitalWrite(buttonPinLeft,HIGH);
digitalWrite(buttonPinRight,HIGH);

  tmrpcm.speakerPin = 9; //5,6,11 or 46 on Mega, 9 on Uno, Nano, etc
  //Complimentary Output or Dual Speakers:
  // Library angepasst, complementary output entfernt - Urs.

  pinMode(10,OUTPUT); //Pin pairs: 9,10 Mega: 5-2,6-7,11-12,46-45 
  
  Serial.begin(115200);
  pinMode(13,OUTPUT); //LED Connected to analog pin 0
  if (!SD.begin(SD_ChipSelectPin)) {  // see if the card is present and can be initialized:
    Serial.println("SD fail");  
    return;   // don't do anything more if not

  }
  else{   
    Serial.println("SD ok");   
  }
  tmrpcm.play(myPlaylist[0]); //the sound file "music" will play each time the arduino powers up, or is reset
}



void loop(){  



while(synth_mode){
  tmrpcm.stopPlayback();
for (int i=0; i < 3000; i++){
  

  v0 = t * ((t>>15|t>>c4)&83&t>>(c4>>3));
    v1 = t * ((t>>14|t>>c4)&83&t>>(c4>>3));

     analogWrite (9, v0);
      analogWrite (10, v1);

     delayMicroseconds(c3);
     t++;

       if(digitalRead(buttonPinRight) == HIGH)c3++;
       if(digitalRead(buttonPinLeft) == HIGH)c3--;



       
}
}



  //blink the LED manually to demonstrate music playback is independant of main loop
 /* if(tmrpcm.isPlaying() && millis() - time > 50 ) {      
      digitalWrite(2,!digitalRead(2));
      time = millis();    
  }else
  if(millis() - time > 500){     
    digitalWrite(2,!digitalRead(2)); 
    time = millis(); 
  }
  */

  if(!tmrpcm.isPlaying())
  {song++;
   if (song>(noSongs-1)) song=0;
   tmrpcm.play(myPlaylist[song]);}

  reading = digitalRead(buttonPinRight);
  if (reading==LOW) {
    song++;
    if (song>(noSongs-1)) song=noSongs-1;
    tmrpcm.play(myPlaylist[song]);
    Serial.println(song);  
    Serial.println(myPlaylist[song]);   
    reading = digitalRead(buttonPinRight);
    if ((reading==LOW)&&(digitalRead(buttonPinLeft)==LOW)) synth_mode=true;
    while(reading==LOW) reading = digitalRead(buttonPinRight);
  };

    reading = digitalRead(buttonPinLeft);
  if (reading==LOW) {
    song--;
     if (song<0) song=0;
    tmrpcm.play(myPlaylist[song]);
    Serial.println(song);  
    Serial.println(myPlaylist[song]);   
    reading = digitalRead(buttonPinLeft);
    while(reading==LOW) reading = digitalRead(buttonPinLeft);
  };


  

  if(Serial.available()){    
    switch(Serial.read()){
    case 'd': tmrpcm.play("music"); break;
    case 'P': tmrpcm.play("temple"); break;
    case 't': tmrpcm.play("catfish"); break;
    case 'p': tmrpcm.pause(); break;
    case '?': if(tmrpcm.isPlaying()){ Serial.println("A wav file is being played");} break;
    case 'S': tmrpcm.stopPlayback(); break;
    case '=': tmrpcm.volume(1); break;
    case '-': tmrpcm.volume(0); break;
    case '0': tmrpcm.quality(0); break;
    case '1': tmrpcm.quality(1); break;
    default: break;
    }
  }

}

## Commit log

2014-12-04 V0.1 PCB Layout
    [Arduino-Fio_v31.brd, Arduino-Fio_v31.sch]
2014-12-04 V 0.11 now with SD card slot
    [Arduino-Fio_v31.brd, Arduino-Fio_v31.sch]
2014-12-09 Finished Routing
    [Arduino-Fio_v31.brd, Arduino-Fio_v31.sch]
2015-01-08 First prototype version, with artwork
    [mixtape.brd, mixtape.sch]
2015-01-08 Old files deleted
    [Arduino-Fio_v31.brd, Arduino-Fio_v31.sch]
2015-03-27 fixed pins_arduino.h - Now Mozzi works!
    [pins_arduino.h]
2016-07-21 Production Verions
    Added repot to https://kitnic.it/ with 1-click BOM
    [BOMmixtape.tsv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]
2016-08-13 Align board edge curve points with line points
    [mixtape.GBL, mixtape.GBO, mixtape.GBP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]
2016-08-13 Specify format in drill file
2016-08-19 corected error on USB port in BOM
    plus minor updates
    [BOMmixtape.tsv, mixtape.brd, mixtape.sch]
2016-08-19 Changed BOM

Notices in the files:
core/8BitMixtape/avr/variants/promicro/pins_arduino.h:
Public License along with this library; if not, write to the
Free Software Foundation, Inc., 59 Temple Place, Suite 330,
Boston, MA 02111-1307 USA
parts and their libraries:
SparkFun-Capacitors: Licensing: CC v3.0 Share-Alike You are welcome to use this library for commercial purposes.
